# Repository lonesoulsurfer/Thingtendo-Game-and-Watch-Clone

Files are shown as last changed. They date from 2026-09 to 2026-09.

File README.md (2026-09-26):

# ESP32 Game & Watch Handheld (Single Screen D-Pad)

<table>
  <tr>
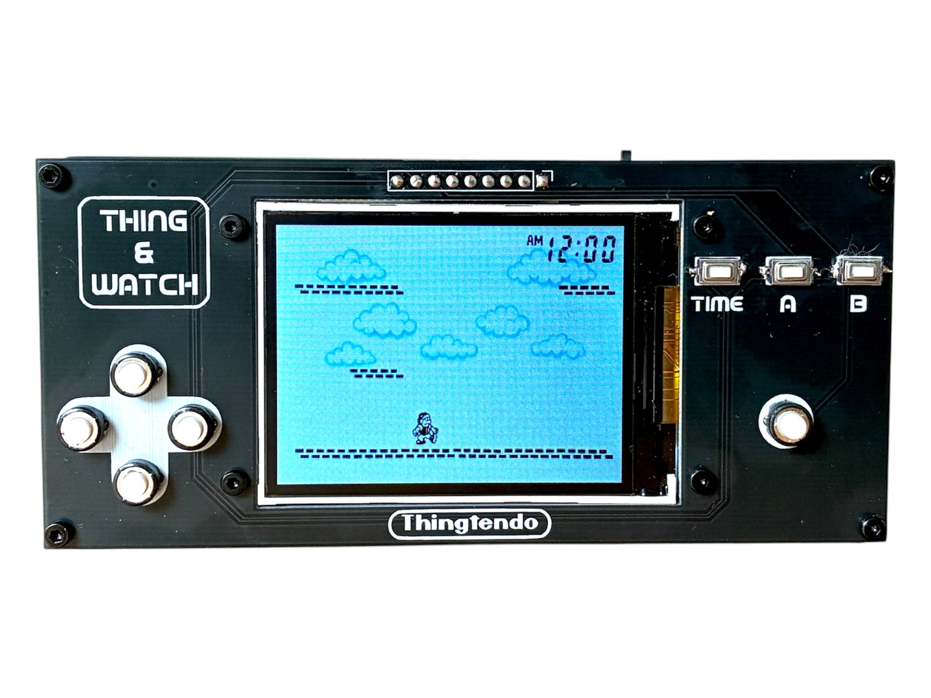
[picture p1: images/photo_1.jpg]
    <td></td>
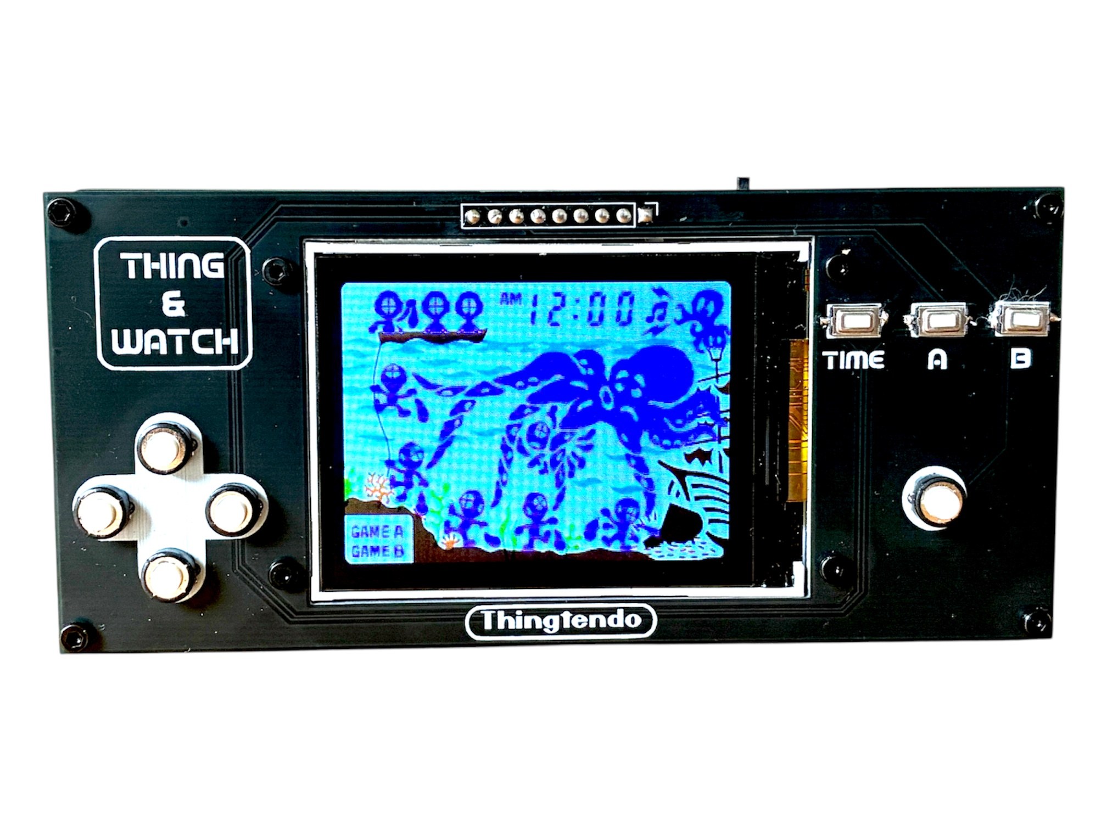
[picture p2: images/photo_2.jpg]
    <td></td>
  </tr>
  <tr>
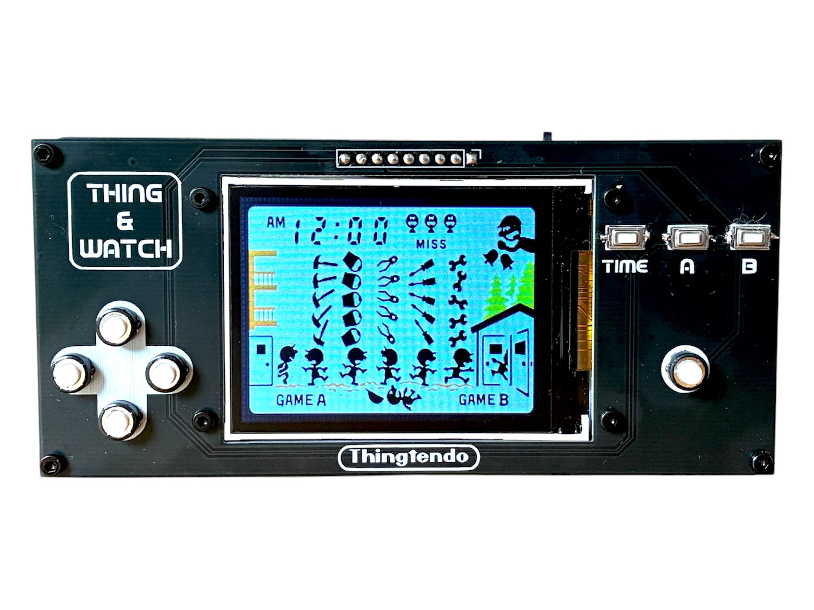
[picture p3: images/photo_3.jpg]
    <td></td>
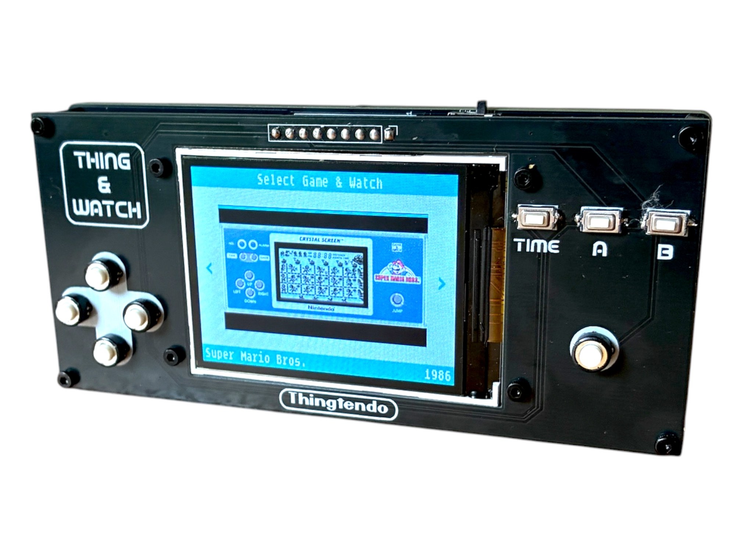
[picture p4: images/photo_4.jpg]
    <td></td>
  </tr>
</table>

A handheld that plays classic Nintendo Game & Watch games on an ESP32-S3, with a 2.4" colour screen, a D-pad, speaker and rechargeable battery.

This is a fork of [slowlane112/Esp32-Game-and-Watch](https://github.com/slowlane112/Esp32-Game-and-Watch). All credit for the original firmware, emulator integration and hardware designs goes to that project. This fork adds a new hardware model, `single_screen_dpad`, plus a few extra features.

Full build guide on Instructables: *(add link)*

## Need help building it?

Upload `CLAUDE_GUIDE.md` to Claude and tell it where you are up to. It will walk you through each step, from setting up the build tools to flashing the firmware.

## What this fork adds

- A new `single_screen_dpad` model: one screen, a 4-way D-pad, a Jump button, Game A, Game B and Time
- 13 games on one device
- Pause
- Continue after a game over (rewinds roughly 10 to 15 seconds)
- Colour mode: an optional colour tint for each game, set from the menu and remembered after power off
- A two-button layout for the games that originally used only a left and a right button

Only the `single_screen_dpad` model has been built and tested with these changes.

## Games

| # | Game | Year | File name |
|---|---|---|---|
| 1 | Donkey Kong Jr. | 1982 | `Game & Watch Donkey Kong Jr. (New Wide Screen).gw` |
| 2 | Balloon Fight | 1986 | `Game & Watch Balloon Fight (Crystal Screen).gw` |
| 3 | Climber | 1986 | `Game & Watch Climber (Crystal Screen).gw` |
| 4 | Super Mario Bros. | 1986 | `Game & Watch Super Mario Bros. (Crystal Screen).gw` |
| 5 | Ball | 1980 | `Game & Watch Ball.gw` |
| 6 | Helmet | 1981 | `Game & Watch Helmet (CN-17 version).gw` |
| 7 | Parachute | 1981 | `Game & Watch Parachute.gw` |
| 8 | Octopus | 1981 | `Game & Watch Octopus.gw` |
| 9 | Popeye | 1981 | `Game & Watch Popeye (Wide Screen).gw` |
| 10 | Fire | 1981 | `Game & Watch Fire (Wide Screen).gw` |
| 11 | Turtle Bridge | 1982 | `Game & Watch Turtle Bridge.gw` |
| 12 | Tropical Fish | 1985 | `Game & Watch Tropical Fish.gw` |
| 13 | Mario the Juggler | 1991 | `Game & Watch Mario The Juggler.gw` |

Game files are not included in this repository. See [Game files](#game-files) below.

## Hardware

| Part | Notes |
|---|---|
| Waveshare ESP32-S3-Zero | Main controller |
| 2.4" 240x320 SPI TFT, ST7789V | Tested with the GMT024-08-SPI8P board (no backlight pin) |
| MAX98357A I2S amplifier module | |
| Small speaker | 4 to 8 ohm |
| USB-C charger / 5V boost module | 18 x 23.6 mm |
| Single cell 3.7V lithium battery | |
| SPDT slide switch | Power |
| 8 x 3x6x2.5mm SMD tactile switches | Left, Right, Up, Down, Jump, Game A, Game B, Time |
| 2 x 100uF capacitors, 1 x 100nF capacitor | Power filtering |
| Male and female 2.54mm headers | Screen and front panel connections |

The build uses three PCBs: a main board, a front panel that holds the screen and buttons, and a back panel. KiCad files are in this repository.

## Wiring

### Buttons

All buttons connect between the GPIO and GND. Internal pull-ups are used, so no resistors are needed.

| Button | GPIO |
|---|---|
| Left | 7 |
| Right | 8 |
| Up | 15 |
| Down | 2 |
| Jump | 1 |
| Game A | 14 |
| Game B | 5 |
| Time | 3 |

GPIO14 and GPIO15 are the small surface pads near the edge of the ESP32-S3-Zero, not header pins, so they need a short wire from the pad to the main board.

### Display (SPI)

| Display pin | Connection |
|---|---|
| GND | GND |
| VCC | 3.3V |
| SCL | GPIO12 |
| SDA | GPIO11 |
| RST | GPIO13 |
| DC | GPIO9 |
| CS | GND |

The display is the only device on the SPI bus, so CS is tied to GND.

### Audio (MAX98357A)

| Amp pin | Connection |
|---|---|
| LRC | GPIO4 |
| BCLK | GPIO10 |
| DIN | GPIO6 |
| GAIN | GND |
| GND | GND |
| VIN | 3.3V |

Tying GAIN to GND gave clean sound with the speaker I used. Leaving it floating caused distortion.

## Controls

### Menu

| Control | Action |
|---|---|
| Left / Right | Choose a game |
| Jump | Load the game |
| Time + Left / Right | Volume down / up |
| Hold Time + Up for 2 seconds | Turn colour mode on or off for the selected game |

### In a game

| Control | Action |
|---|---|
| Game A / Game B | Start game A or game B |
| Tap Time | Pause / resume |
| Time + Left / Right | Volume down / up |
| Hold Time + Down for 2 seconds | Back to the menu |
| Hold Time + Up for 2 seconds | Continue after a game over |

Donkey Kong Jr., Balloon Fight, Climber and Super Mario Bros. use the D-pad and Jump as normal.

The other nine games were originally played with a left and a right button. On this handheld, **D-pad Right** moves left and **Jump** moves right, so there is one button under each thumb.

Continue works by keeping a short history of the game in memory. Use it within about 10 seconds of the game ending. Your score goes back to what it was at that point too.

## Game files

The game files (`.gw`) are made from original Game & Watch ROMs and MAME artwork. They are not included here, and you need to supply your own.

1. For each game, you need the MAME ROM zip and the matching MAME artwork zip, both with the same short name (for example `gnw_dkjr.zip`).
2. Convert them with [LCD-Game-Shrinker](https://github.com/bzhxx/LCD-Game-Shrinker). Put the ROM zip in `input/rom/` and the artwork zip in `input/artwork/`, then run:

   ```
   python3 shrink_it.py input/rom/gnw_dkjr.zip
   ```

   If you have ESP-IDF active in the same terminal, use `/usr/bin/python3` instead. The ESP-IDF Python does not have the libraries the shrinker needs.

3. Copy the finished `.gw` files from LCD-Game-Shrinker's `output/` folder into `gandw_handheld/main/`. The names must match the table above exactly.

MAME short names for the games in this build:

| Game | Short name |
|---|---|
| Donkey Kong Jr. | `gnw_dkjr` |
| Balloon Fight | `gnw_bfight` |
| Climber | `gnw_climber` |
| Super Mario Bros. | `gnw_smb` |
| Ball | `gnw_ball` |
| Helmet | `gnw_helmet` |
| Parachute | `gnw_pchute` |
| Octopus | `gnw_octopus` |
| Popeye | `gnw_popeye` |
| Fire (Wide Screen) | `gnw_fire` |
| Turtle Bridge | `gnw_tbridge` |
| Tropical Fish | `gnw_tfish` |
| Mario the Juggler | `gnw_mariotj` |

## Building the firmware

This was built with ESP-IDF v6.0 on Ubuntu.

```
source ~/esp/esp-idf/export.sh
cd gandw_handheld
idf.py -DMODEL=single_screen_dpad -DDISPLAY=st7789 build
```

Both flags are needed. Without `-DDISPLAY=st7789` the build defaults to the ILI9341 driver, and the screen will not work with an ST7789V panel.

## Flashing

With the board connected over USB:

```
idf.py -p PORT flash
```

Or with esptool, from the `gandw_handheld/build` folder:

```
python -m esptool --chip esp32s3 -b 460800 --port PORT --before default-reset --after hard-reset write-flash --flash-mode dio --flash-size 4MB --flash-freq 80m 0x0 bootloader/bootloader.bin 0x8000 partition_table/partition-table.bin 0xe000 ota_data_initial.bin 0x10000 gandw_handheld.bin
```

Replace `PORT` with your serial port, for example `COM4` on Windows or `/dev/ttyACM0` on Linux.

If it gets stuck on "Connecting...", hold BOOT, tap RESET, release BOOT and try again.

## Adding more games

Each game uses roughly 130 to 160 KB of flash (the game file plus its menu icon). With 13 games the firmware is about 2 MB of the 3 MB app partition.

To add a game:

1. Convert it with LCD-Game-Shrinker and copy the `.gw` file into `gandw_handheld/main/`.
2. Add the file name to the `single_screen_dpad` list in `gandw_handheld/main/CMakeLists.txt`.
3. Add an entry to the `games[]` list and a matching ROM entry in `game_load()` in `gandw_handheld/main/game.c`.
4. Add its menu icon to `menu_single_screen_dpad.raw` in the same position as its entry in `games[]`.
5. Add a tint colour for it in `game_tints[]` if you want colour mode.

Tropical Fish swaps Game A and Game B in the button code, and that is tied to its position in the list. If you insert a game before it, update that index in `button.c`.

## Credits

- [slowlane112/Esp32-Game-and-Watch](https://github.com/slowlane112/Esp32-Game-and-Watch): the original project this is based on
- [bzhxx](https://github.com/bzhxx): LCD Game Emulator and LCD-Game-Shrinker
- MAME and the MAME artwork community: the ROM and artwork sets the game files are built from

## License

GPL-3.0, the same as the original project. See [LICENSE](LICENSE).

Game & Watch is a trademark of Nintendo. This project is not affiliated with or endorsed by Nintendo.

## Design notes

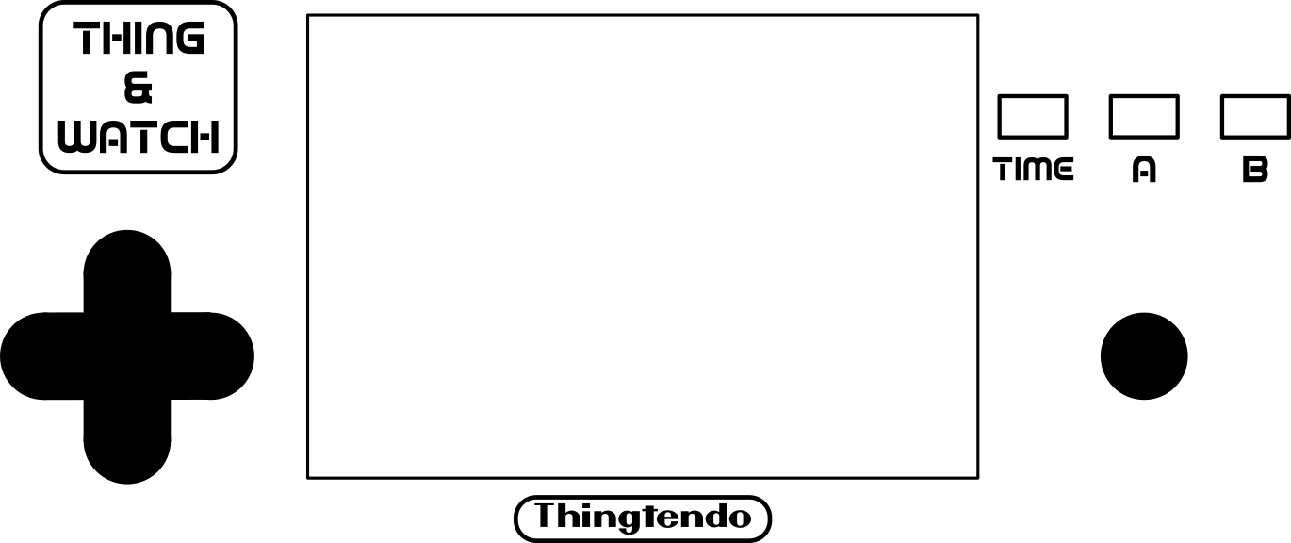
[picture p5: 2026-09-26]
Kicad_Panel_Design/Kicad_Front Panel/Front_Panel_Design/GW - Front Panel.png

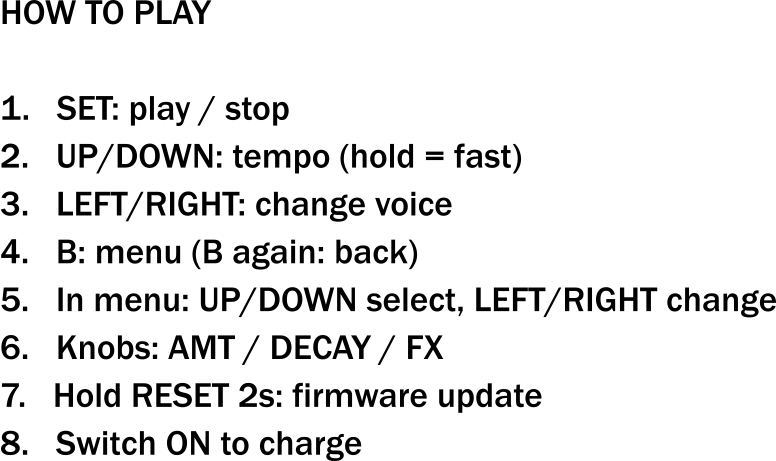
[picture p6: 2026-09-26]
Kicad_Panel_Design/Kicad_Back Panel/Back_Panel_Design/text1.png

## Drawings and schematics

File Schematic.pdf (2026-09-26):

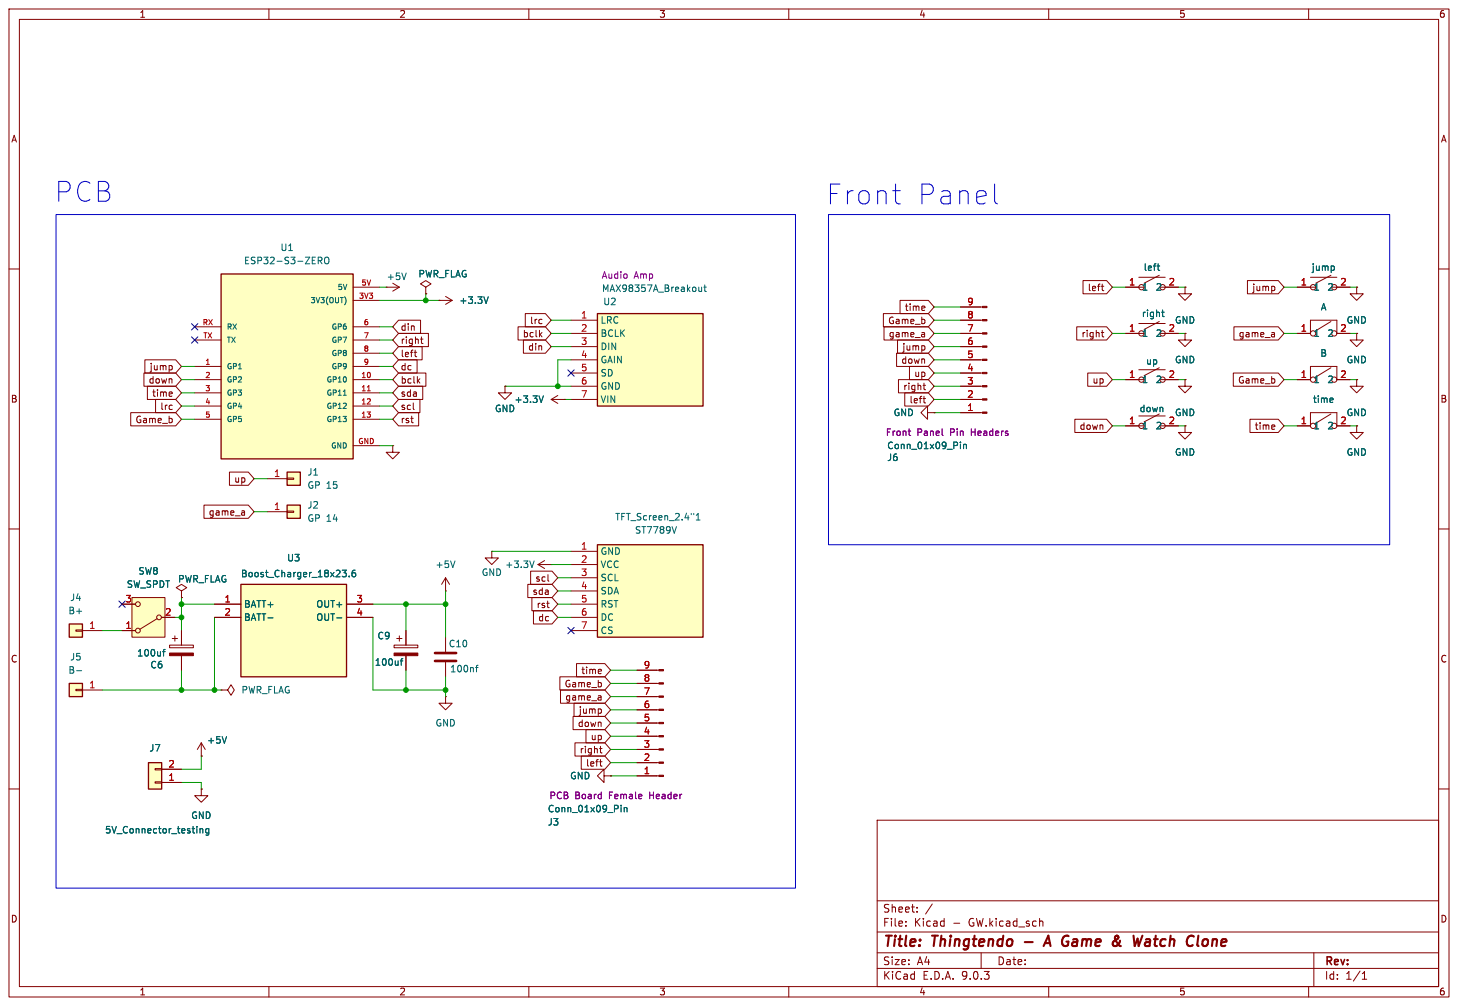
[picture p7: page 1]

J6Conn_01x09_Pin Front Panel Pin Headers 1

J3Conn_01x09_Pin PCB Board Female Header GND GND

right
J3Conn_01x09_Pin PCB Board Female Header 1

Id: 1/1 Title: Thingtendo - A Game & Watch Clone

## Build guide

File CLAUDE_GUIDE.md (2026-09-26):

# Build Assistant Guide: ESP32 Game & Watch Handheld

## For people using this file

If you are new to ESP32 projects, Linux or building firmware, you can get step by step help from Claude (or another AI assistant):

1. Start a new chat with Claude.
2. Upload this file (`CLAUDE_GUIDE.md`).
3. Tell it where you are up to, for example: "I have all the parts and want to build the firmware. I use Windows."

It will walk you through one step at a time and help you fix problems along the way.

Everything below this line is written for the assistant.

---

## Instructions for the assistant

You are helping someone build the ESP32 Game & Watch handheld from this repository. They may be a beginner. Follow these rules:

- **Go one step at a time.** Give one step, ask the user to run it and paste the output, then check the output before moving on. Do not dump every step at once.
- **Verify, do not assume.** After each command, check the output for errors, wrong file sizes, wrong names or old timestamps. Many problems in this build come from a file that did not copy, or a command run in the wrong folder or the wrong terminal.
- **Ask about their setup first:** Windows, Mac or Linux; whether they use a Linux virtual machine; whether they have soldered the hardware yet; and what they want to do (flash, build, add games, fix a problem).
- **Explain briefly and plainly.** Say what a step does in one sentence, without jargon.
- **Do not help find or download ROMs or artwork.** The user must supply their own. You can explain what files are needed and how to convert them.
- **Never ask for secrets.** If the user shares a GitHub token or password, tell them to revoke it and make a new one.
- **Say when you are unsure,** and suggest a way to check rather than guessing.

## Project overview

A handheld that plays Nintendo Game & Watch games on an ESP32-S3. It is a fork of [slowlane112/Esp32-Game-and-Watch](https://github.com/slowlane112/Esp32-Game-and-Watch) and adds a new firmware model called `single_screen_dpad`.

Features added in this fork:
- 13 games on one device
- Pause, continue after a game over, and a per-game colour mode
- A two-button layout for the games that originally had only a left and a right button

## Repository layout

| Path | Contents |
|---|---|
| `gandw_handheld/` | Firmware project (ESP-IDF) |
| `gandw_handheld/main/` | Firmware source. The `.gw` game files also go here (not included) |
| `components/lcd_game_emulator/` | The Game & Watch emulator |
| `assets/menu/` | Menu icon images and scripts from the original project |
| `Kicad_GW/`, `Kicad_Panel_Design/` | KiCad files for the main board, front panel and back panel |
| `Gerber_Files/` | Gerbers ready to send to a PCB maker |
| `Schematic.pdf` | Schematic |

## Hardware

- Waveshare ESP32-S3-Zero
- 2.4" 240x320 SPI TFT with ST7789V driver (tested with GMT024-08-SPI8P, which has no backlight pin)
- MAX98357A I2S amplifier module and a 4 to 8 ohm speaker
- USB-C charger / 5V boost module (18 x 23.6 mm) and a single cell lithium battery
- SPDT power switch
- 8 tactile switches: Left, Right, Up, Down, Jump, Game A, Game B, Time
- 2 x 100uF and 1 x 100nF capacitors
- 2.54mm male and female headers

## Wiring

### Buttons (each button between the GPIO and GND, internal pull-ups, no resistors)

| Button | GPIO |
|---|---|
| Left | 7 |
| Right | 8 |
| Up | 15 |
| Down | 2 |
| Jump | 1 |
| Game A | 14 |
| Game B | 5 |
| Time | 3 |

GPIO14 and GPIO15 are small surface pads on the ESP32-S3-Zero, not header pins. They need a short wire from the pad to the board.

### Display

| Display pin | Connection |
|---|---|
| GND | GND |
| VCC | 3.3V |
| SCL | GPIO12 |
| SDA | GPIO11 |
| RST | GPIO13 |
| DC | GPIO9 |
| CS | GND |

### Audio (MAX98357A)

| Amp pin | Connection |
|---|---|
| LRC | GPIO4 |
| BCLK | GPIO10 |
| DIN | GPIO6 |
| GAIN | GND |
| GND | GND |
| VIN | 3.3V |

## The overall process

1. Set up a Linux build environment with ESP-IDF.
2. Get the game files: the user supplies MAME ROM and artwork zips, then converts them with LCD-Game-Shrinker.
3. Build the firmware.
4. Flash it to the ESP32-S3-Zero.
5. Test the controls.

Ready made firmware is not provided, because the finished firmware contains the game data. Everyone builds their own.

## Step 1: Build environment

The firmware was built on Ubuntu with ESP-IDF v6.0. Windows users can use an Ubuntu virtual machine (for example VirtualBox) or WSL.

- Install ESP-IDF v6.0 for the ESP32-S3, following Espressif's official ESP-IDF Getting Started guide for Linux. Check the exact version tag and install commands with the user against that guide rather than from memory.
- Clone this repository.
- In **every new terminal**, run `source ~/esp/esp-idf/export.sh` (adjust the path if ESP-IDF was installed elsewhere) before using `idf.py`. If `idf.py` gives "command not found", this is almost always why.

If the user works in a VirtualBox VM with a shared folder:
- Files copied through the shared folder sometimes do not update. Always check sizes and timestamps with `ls -la` (Linux) or `dir` (Windows) after copying.
- Clipboard sharing is under Devices > Shared Clipboard > Bidirectional. In the Linux terminal, paste with Ctrl+Shift+V, not Ctrl+V.
- Linux paths are case sensitive (`ROM` is not the same as `rom`).

## Step 2: Game files

Each game needs two zips with the same MAME short name: a ROM zip (small, tens of KB) and an artwork zip (usually several MB, containing PNG files and `default.lay`). If a "ROM" zip is several MB and contains PNGs, it is actually artwork.

Convert them with [LCD-Game-Shrinker](https://github.com/bzhxx/LCD-Game-Shrinker):
1. Install it and its requirements as described in its README.
2. Put the ROM zip in `input/rom/` and the artwork zip in `input/artwork/`.
3. Run `python3 shrink_it.py input/rom/<shortname>.zip`.
4. The finished file appears in `output/`, for example `Game & Watch Ball.gw`.

Important: if ESP-IDF's `export.sh` has been run in the same terminal, `python3` points to ESP-IDF's Python, which does not have `lxml`. Use `/usr/bin/python3 shrink_it.py ...` or a fresh terminal. The error looks like `No module named 'lxml'`.

A NumPy `DeprecationWarning` during conversion is harmless.

Copy the `.gw` files into `gandw_handheld/main/`. The names must match exactly:

| # | Game | Short name | File name |
|---|---|---|---|
| 0 | Donkey Kong Jr. | `gnw_dkjr` | `Game & Watch Donkey Kong Jr. (New Wide Screen).gw` |
| 1 | Balloon Fight | `gnw_bfight` | `Game & Watch Balloon Fight (Crystal Screen).gw` |
| 2 | Climber | `gnw_climber` | `Game & Watch Climber (Crystal Screen).gw` |
| 3 | Super Mario Bros. | `gnw_smb` | `Game & Watch Super Mario Bros. (Crystal Screen).gw` |
| 4 | Ball | `gnw_ball` | `Game & Watch Ball.gw` |
| 5 | Helmet | `gnw_helmet` | `Game & Watch Helmet (CN-17 version).gw` |
| 6 | Parachute | `gnw_pchute` | `Game & Watch Parachute.gw` |
| 7 | Octopus | `gnw_octopus` | `Game & Watch Octopus.gw` |
| 8 | Popeye | `gnw_popeye` | `Game & Watch Popeye (Wide Screen).gw` |
| 9 | Fire | `gnw_fire` | `Game & Watch Fire (Wide Screen).gw` |
| 10 | Turtle Bridge | `gnw_tbridge` | `Game & Watch Turtle Bridge.gw` |
| 11 | Tropical Fish | `gnw_tfish` | `Game & Watch Tropical Fish.gw` |
| 12 | Mario the Juggler | `gnw_mariotj` | `Game & Watch Mario The Juggler.gw` |

If any game file is missing, the build fails. Check with `ls gandw_handheld/main/*.gw | wc -l`, which should print 13.

## Step 3: Build

```
source ~/esp/esp-idf/export.sh
cd gandw_handheld
rm -rf build
idf.py -DMODEL=single_screen_dpad -DDISPLAY=st7789 build
```

- Both `-D` flags are required. Without `-DDISPLAY=st7789`, the build silently uses the ILI9341 driver and the ST7789V screen will not work.
- Success ends with "Project build complete". The size line should show the app at about 2 MB of a 3 MB (`0x300000`) partition.
- When searching the log for errors, lines like `error.c.obj` are just file names, not errors. Look for `error:`.
- If the build fails after files were renamed or added, clear the build folder with `rm -rf build` and try again.

## Step 4: Flash

The files needed are in `gandw_handheld/build/`: `bootloader/bootloader.bin`, `partition_table/partition-table.bin`, `ota_data_initial.bin` and `gandw_handheld.bin`.

From Linux with the board connected:
```
idf.py -p PORT flash
```

From Windows (easiest if the build was done in a VM): install Python and esptool (`pip install esptool`), find the COM port in Device Manager under Ports (COM & LPT), copy the four files into one folder, open a terminal in that folder, then run:
```
python -m esptool --chip esp32s3 -b 460800 --port COMx --before default-reset --after hard-reset write-flash --flash-mode dio --flash-size 4MB --flash-freq 80m 0x0 bootloader.bin 0x8000 partition-table.bin 0xe000 ota_data_initial.bin 0x10000 gandw_handheld.bin
```

- "No such file or directory" for a `.bin` file means the terminal is in the wrong folder. Use `cd` to the folder first, with quotes around paths that contain spaces.
- If it hangs at "Connecting...", hold BOOT, tap RESET, release BOOT and try again.
- Success ends with "Hash of data verified" for each file.
- After every rebuild, copy all four files again and check their timestamps before flashing.

## Step 5: Controls

### Menu

| Control | Action |
|---|---|
| Left / Right | Choose a game |
| Jump | Load the game |
| Time + Left / Right | Volume |
| Hold Time + Up for 2 seconds | Toggle colour mode for the selected game (beeps, remembered after power off) |

### In a game

| Control | Action |
|---|---|
| Game A / Game B | Start game A or game B |
| Tap Time | Pause / resume |
| Time + Left / Right | Volume |
| Hold Time + Down for 2 seconds | Back to the menu |
| Hold Time + Up for 2 seconds | Continue after a game over (use within about 10 seconds) |

Games 0 to 3 use the D-pad and Jump normally. For Donkey Kong Jr., the key is grabbed with Jump + Left at the edge of the top branch.

Games 4 to 12 use a two-button layout: D-pad Right moves left and Jump moves right.

## Troubleshooting

| Symptom | Likely cause |
|---|---|
| Screen blank or garbled | Built without `-DDISPLAY=st7789`, or SPI wiring wrong |
| Colours look like a negative | Colour inversion setting in `display.c` (`esp_lcd_panel_invert_color` in `display_setup_lcd_1`) does not suit this panel batch |
| Picture upside down | Mirror settings in `display_setup_lcd_1` in `display.c` |
| Sound distorted | MAX98357A GAIN pin floating. Tie it to GND |
| Left and Right reversed | Swap the GPIO numbers for `BUTTON_LEFT` and `BUTTON_RIGHT` in the `MODEL_SINGLE_SCREEN_DPAD` block of `button.c` |
| A game always starts in Game B, or a button seems stuck | Check for a faulty or shorted switch with a multimeter (GPIO to GND should only beep when pressed) |
| Wrong game or icon for a menu entry | The order of `games[]`, `game_load()` and the icons in `menu_single_screen_dpad.raw` does not match |
| `idf.py: command not found` | ESP-IDF not sourced in this terminal |
| Build error `undefined reference to _binary_...` | A `.gw` file is missing or named differently from the list |

### A useful debugging technique

To see exactly which button signals the firmware sends to a game, temporarily add a log line in `button_get_dpad_buttons()` in `button.c` that prints `hw_buttons` only when it changes, add `#include "esp_log.h"`, then watch the output with `python -m serial.tools.miniterm COMx 115200`. Values: `0x01` Left, `0x02` Up, `0x04` Right, `0x08` Down, `0x10` A (Jump), `0x40` Time (Game B), `0x80` Game (Game A). A value that stays set with nothing pressed points to a hardware fault. Remove the log line afterwards.

## Code notes for changes

- The model's button pins, combos (pause, continue, menu return) and the two-button remap are in `gandw_handheld/main/button.c`.
- Game list, ROM loading and colour tints are in `gandw_handheld/main/game.c`. `game_count` is worked out automatically from `games[]`.
- Colour mode on/off settings are stored in NVS as two 8-bit values: `color_mask` (games 0 to 7) and `color_mask2` (games 8 to 15).
- Continue uses the emulator's `gw_state_save` / `gw_state_load` in `main.c`, called between frames, never from inside the button code.
- Tropical Fish swaps Game A and Game B, tied to its position (index 11) in `button.c`. If games are inserted before it, update that index.
- The two-button remap applies to index 4 and above. Adding a game that needs the normal D-pad means changing that rule.
- Each game costs about 130 to 160 KB of flash (game file plus uncompressed menu icon). About 1 MB is free with 13 games.
- Menu icons are stored in `menu_single_screen_dpad.raw` as raw RGB565, little endian, one icon after another in the same order as `games[]`. Each entry's `img_unit_width` and `img_unit_height` must match its icon size exactly.

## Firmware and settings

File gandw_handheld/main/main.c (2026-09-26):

#include "esp_timer.h"
#include "freertos/FreeRTOS.h"
#include <gw_system.h>
#include "button.h"
#include "nvs.h"
#include "menu.h"
#include "game.h"
#include "battery.h"
#include "volume.h"
#include "display.h"
#include "audio.h"

static void display_volume_battery(unsigned short *framebuffer)
{
	if (volume_display_count > 0) {
		volume_display(framebuffer);
	}
	if (battery_display_count > 0) {
		battery_display(framebuffer);
	}
}

static void reset_system(unsigned short *framebuffer)
{
	display_blank_screen(framebuffer);
	esp_restart();
}

static void state_menu(unsigned short *framebuffer) {
	
	menu_index = game_get_selected();
	menu_update = true;
	
	while (menu_show) {
		
		menu_buttons_process();
		
		if (volume_display_count > 0) {
			volume_display_count--;
			if (volume_display_count == 0) {
				menu_update = true;
			}
		}

		if (battery_display_count > 0) {
			battery_display_count--;
			if (battery_display_count == 0) {
				menu_update = true;
			}
		}
		
		if (button_start_delay > 0) {
			button_start_delay--;
		}
			
		if (menu_update && !display_transfer_in_progress) {
			
			menu_display_item(framebuffer, menu_index);
			
			if (volume_display_count > 0 || battery_display_count > 0) {
				display_volume_battery(framebuffer);
			}

			display_render_screen(framebuffer);
			
			menu_update = false;
			
		}
		
		vTaskDelay(pdMS_TO_TICKS(8)); 
		
	}
	
}

static void state_game(unsigned short *framebuffer, uint16_t *audio_buffer) {
	
	size_t audio_buffer_size = GW_AUDIO_BUFFER_LENGTH * sizeof(uint16_t);
	
	button_start_delay = 63;
	
	game_load(menu_index);

	gw_system_romload();
	gw_system_sound_init();
	gw_system_config();
	gw_system_start();
	gw_system_reset();
	
	/* Continue/rewind: snapshot ring, cleared for each new game */
	extern volatile bool rewind_requested;
	static gw_state_t rewind_slots[3];
	int rewind_count = 0;
	int rewind_next = 0;
	int64_t rewind_last_save = esp_timer_get_time();
	rewind_requested = false;
	extern volatile bool game_paused;
	game_paused = false;

	while (!menu_show) {

		if (volume_display_count > 0) {
			volume_display_count--;
		}

		if (battery_display_count > 0) {
			battery_display_count--;
		}
		
		if (button_start_delay > 0) {
			button_start_delay--;
		}

#ifdef MODEL_SINGLE_SCREEN_DPAD
		{
			extern void button_process_pause(void);
			button_process_pause();
		}
		if (game_paused) {
			/* frozen: keep feeding silence so timing stays steady and sound stops */
			for (size_t i = 0; i < GW_AUDIO_BUFFER_LENGTH; i++) audio_buffer[i] = 0;
			size_t bytes_written_pause;
			i2s_channel_write(audio_handle, audio_buffer, audio_buffer_size, &bytes_written_pause, portMAX_DELAY);
			continue;
		}
#endif

		if (rewind_requested) {
			rewind_requested = false;
			if (rewind_count > 0) {
				int oldest = (rewind_next - rewind_count + 3) % 3;
				gw_state_load(&rewind_slots[oldest]);
				rewind_next = (oldest + 1) % 3;
				rewind_count = 1;
				rewind_last_save = esp_timer_get_time();
			}
		}
		else if (esp_timer_get_time() - rewind_last_save > 5000000) {
			gw_state_save(&rewind_slots[rewind_next]);
			rewind_next = (rewind_next + 1) % 3;
			if (rewind_count < 3) rewind_count++;
			rewind_last_save = esp_timer_get_time();
		}

		gw_system_run(GW_SYSTEM_CYCLES);
		

		// lcd
		if (!display_transfer_in_progress) {

			display_transfer_in_progress = true;

			gw_system_blit(framebuffer);

			if (volume_display_count > 0 || battery_display_count > 0) {
				display_volume_battery(framebuffer);
			}

			display_render_screen(framebuffer);

		}

		// audio
	
		for (size_t i = 0; i < GW_AUDIO_BUFFER_LENGTH; i++) 
		{
			audio_buffer[i] = (gw_audio_buffer[i] > 0) * volume;
		}

		size_t bytes_written;

		i2s_channel_write(audio_handle, audio_buffer, audio_buffer_size, &bytes_written, portMAX_DELAY);

		gw_audio_buffer_copied = true;
		

	}
	
}

void app_main(void)
{

	// memory for sound and screen
	uint16_t *framebuffer = (uint16_t *)heap_caps_malloc(GW_SCREEN_WIDTH * GW_SCREEN_HEIGHT * sizeof(uint16_t), MALLOC_CAP_DMA | MALLOC_CAP_INTERNAL);
	uint16_t audio_buffer[GW_AUDIO_BUFFER_LENGTH];

	audio_init();
	display_init();
	button_init();
	nvs_init();
	
	display_blank_screen(framebuffer);

	volume_read();

	battery_get_level();
	
	state_menu(framebuffer);
	
	state_game(framebuffer, audio_buffer);
	
	reset_system(framebuffer);
	
}

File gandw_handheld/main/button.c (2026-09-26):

#include "driver/gpio.h"
#include "esp_timer.h"
#include <gw_system.h>
#include "button.h"
#include "volume.h"
#include "audio.h"
#include "menu.h"
#include "game.h"
#include "gw_graphic.h"
volatile bool rewind_requested = false;
volatile bool game_paused = false;

// buttons
#define BUTTON_GAME_A		GPIO_NUM_14
#define BUTTON_GAME_B		GPIO_NUM_5
#define BUTTON_TIME			GPIO_NUM_3
#define BUTTON_ALARM		GPIO_NUM_7
#define BUTTON_ACL			GPIO_NUM_8

#if defined(MODEL_SINGLE_SCREEN_2_BUTTON) || defined(MODEL_SINGLE_SCREEN_4_BUTTON) || defined(MODEL_MULTI_SCREEN_2_BUTTON)
	#define BUTTON_LEFT			GPIO_NUM_2
	#define BUTTON_RIGHT		GPIO_NUM_1
#endif

#if defined(MODEL_SINGLE_SCREEN_4_BUTTON)
	#define BUTTON_LEFT_2		GPIO_NUM_17
	#define BUTTON_RIGHT_2		GPIO_NUM_18
#endif

#if defined(MODEL_MULTI_SCREEN_DPAD)
	#define BUTTON_LEFT				GPIO_NUM_41
	#define BUTTON_RIGHT			GPIO_NUM_40
	#define BUTTON_UP				GPIO_NUM_42
	#define BUTTON_DOWN				GPIO_NUM_2
	#define BUTTON_JUMP				GPIO_NUM_1
#elif defined(MODEL_SINGLE_SCREEN_DPAD)
	// Custom pin assignment: avoids bottom-row GPIOs (40/41/42) on the
	// ESP32-S3-Zero module for easier PCB layout. See wiring_list.md.
	#define BUTTON_LEFT				GPIO_NUM_7
	#define BUTTON_RIGHT			GPIO_NUM_8
	#define BUTTON_UP				GPIO_NUM_15
	#define BUTTON_DOWN				GPIO_NUM_2
	#define BUTTON_JUMP				GPIO_NUM_1
#endif

// group buttons

#if defined(MODEL_SINGLE_SCREEN_2_BUTTON) || defined(MODEL_MULTI_SCREEN_2_BUTTON)
	static const int left_group_buttons[]  = { BUTTON_LEFT };
	static const int right_group_buttons[] = { BUTTON_RIGHT };
#elif defined(MODEL_SINGLE_SCREEN_4_BUTTON)
	static const int left_group_buttons[]  = { BUTTON_LEFT, BUTTON_LEFT_2 };
	static const int right_group_buttons[] = { BUTTON_RIGHT, BUTTON_RIGHT_2 };
#elif defined(MODEL_MULTI_SCREEN_DPAD) || defined(MODEL_SINGLE_SCREEN_DPAD)
	static const int left_group_buttons[]  = { BUTTON_LEFT };
	static const int right_group_buttons[] = { BUTTON_RIGHT };	
#endif

#if defined(MODEL_SINGLE_SCREEN_DPAD)
	/* Left+Jump is DK Jr key-grab move, so menu return uses Time+Down */
	static const int start_button = GPIO_NUM_1;
	static const int reset_button_1 = BUTTON_TIME;
	static const int reset_button_2 = BUTTON_DOWN;
#elif defined(MODEL_MULTI_SCREEN_DPAD)
	static const int start_button = GPIO_NUM_1;
	static const int reset_button_1 = BUTTON_LEFT;
	static const int reset_button_2 = BUTTON_JUMP;
#else
	static const int start_button = BUTTON_GAME_A;
	static const int reset_button_1 = BUTTON_LEFT;
	static const int reset_button_2 = BUTTON_RIGHT;	
#endif

button_control_type_t button_control_type = BUTTON_CONTROL_TYPE_NONE;
button_control_mode_t button_control_mode = BUTTON_CONTROL_MODE_NONE;

uint8_t button_start_delay = 63;
int64_t button_reset_timer = 0;

void button_init(void) {

	esp_rom_gpio_pad_select_gpio(BUTTON_GAME_B);
	gpio_set_direction(BUTTON_GAME_B, GPIO_MODE_INPUT);
	gpio_set_pull_mode(BUTTON_GAME_B, GPIO_PULLUP_ONLY);
	
	esp_rom_gpio_pad_select_gpio(BUTTON_TIME);
	gpio_set_direction(BUTTON_TIME, GPIO_MODE_INPUT);
	gpio_set_pull_mode(BUTTON_TIME, GPIO_PULLUP_ONLY);

	esp_rom_gpio_pad_select_gpio(BUTTON_GAME_A);
	gpio_set_direction(BUTTON_GAME_A, GPIO_MODE_INPUT);
	gpio_set_pull_mode(BUTTON_GAME_A, GPIO_PULLUP_ONLY);

	esp_rom_gpio_pad_select_gpio(BUTTON_ALARM);
	gpio_set_direction(BUTTON_ALARM, GPIO_MODE_INPUT);
	gpio_set_pull_mode(BUTTON_ALARM, GPIO_PULLUP_ONLY);

	esp_rom_gpio_pad_select_gpio(BUTTON_ACL);
	gpio_set_direction(BUTTON_ACL, GPIO_MODE_INPUT);
	gpio_set_pull_mode(BUTTON_ACL, GPIO_PULLUP_ONLY);

#if defined(MODEL_SINGLE_SCREEN_2_BUTTON) || defined(MODEL_SINGLE_SCREEN_4_BUTTON) || defined(MODEL_MULTI_SCREEN_2_BUTTON)
	esp_rom_gpio_pad_select_gpio(BUTTON_LEFT);
	gpio_set_direction(BUTTON_LEFT, GPIO_MODE_INPUT);
	gpio_set_pull_mode(BUTTON_LEFT, GPIO_PULLUP_ONLY);

	esp_rom_gpio_pad_select_gpio(BUTTON_RIGHT);
	gpio_set_direction(BUTTON_RIGHT, GPIO_MODE_INPUT);
	gpio_set_pull_mode(BUTTON_RIGHT, GPIO_PULLUP_ONLY);
#endif
	
#if defined(MODEL_SINGLE_SCREEN_4_BUTTON)	
	esp_rom_gpio_pad_select_gpio(BUTTON_LEFT_2);
	gpio_set_direction(BUTTON_LEFT_2, GPIO_MODE_INPUT);
	gpio_set_pull_mode(BUTTON_LEFT_2, GPIO_PULLUP_ONLY);

	esp_rom_gpio_pad_select_gpio(BUTTON_RIGHT_2);
	gpio_set_direction(BUTTON_RIGHT_2, GPIO_MODE_INPUT);
	gpio_set_pull_mode(BUTTON_RIGHT_2, GPIO_PULLUP_ONLY);
#endif

#if defined(MODEL_MULTI_SCREEN_DPAD) || defined(MODEL_SINGLE_SCREEN_DPAD)

	esp_rom_gpio_pad_select_gpio(BUTTON_LEFT);
	gpio_set_direction(BUTTON_LEFT, GPIO_MODE_INPUT);
	gpio_set_pull_mode(BUTTON_LEFT, GPIO_PULLUP_ONLY);

	esp_rom_gpio_pad_select_gpio(BUTTON_RIGHT);
	gpio_set_direction(BUTTON_RIGHT, GPIO_MODE_INPUT);
	gpio_set_pull_mode(BUTTON_RIGHT, GPIO_PULLUP_ONLY);
	
	esp_rom_gpio_pad_select_gpio(BUTTON_UP);
	gpio_set_direction(BUTTON_UP, GPIO_MODE_INPUT);
	gpio_set_pull_mode(BUTTON_UP, GPIO_PULLUP_ONLY);

	esp_rom_gpio_pad_select_gpio(BUTTON_DOWN);
	gpio_set_direction(BUTTON_DOWN, GPIO_MODE_INPUT);
	gpio_set_pull_mode(BUTTON_DOWN, GPIO_PULLUP_ONLY);
	
	esp_rom_gpio_pad_select_gpio(BUTTON_JUMP);
	gpio_set_direction(BUTTON_JUMP, GPIO_MODE_INPUT);
	gpio_set_pull_mode(BUTTON_JUMP, GPIO_PULLUP_ONLY);

#endif

}

static bool process_reset_buttons(void) {
	
	if (gpio_get_level(reset_button_1) == 0 && gpio_get_level(reset_button_2) == 0) { 
			
		if (button_reset_timer == 0) {
			button_reset_timer = esp_timer_get_time();
		}
		else {
			if (esp_timer_get_time() - button_reset_timer > 2000000) {
				menu_show = true;
			}
		}
		
		return true;
	}
	else {
		button_reset_timer = 0;
	}
	
	return false;
}
static int64_t color_mode_timer = 0;
static bool color_mode_active = false;
static bool color_mode_wait_release = false;
/* Easter egg: hold Time + Jump for 2 seconds to toggle a colour
   tint over the current game, using a different colour per game.
   The wait_release latch stops it from rapidly re-toggling every
   frame for as long as the combo stays held past the threshold. */
static bool process_color_mode_buttons(void) {
	
	if (gpio_get_level(BUTTON_TIME) == 0 && gpio_get_level(BUTTON_JUMP) == 0) {
		
		if (color_mode_wait_release) {
			return true;
		}
		
		if (color_mode_timer == 0) {
			color_mode_timer = esp_timer_get_time();
		}
		else if (esp_timer_get_time() - color_mode_timer > 2000000) {
			
			static const uint16_t game_tints[4] = {
				0xF800, /* DK Jr - red */
				0xF81F, /* Balloon Fight - magenta */
				0x07FF, /* Climber - cyan */
				0x07E0  /* SMB - bright green */
			};
			
			color_mode_active = !color_mode_active;
			color_mode_wait_release = true;
			
			uint16_t tint = 0xffff;
			if (g_current_game_index < 4) {
				tint = game_tints[g_current_game_index];
			}
			gw_gfx_set_color_mode(color_mode_active ? 1 : 0, tint);
		}
		
		return true;
	}
	else {
		color_mode_timer = 0;
		color_mode_wait_release = false;
	}
	
	return false;
}
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
